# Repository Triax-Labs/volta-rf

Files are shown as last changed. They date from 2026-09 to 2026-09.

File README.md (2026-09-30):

# VoltaRF

VoltaRF is a homebrew software defined radio (SDR), it is based on parts found inside a cheap 'n old satellite DVB-S television receiver.





VoltaRF could Also be used as a good ol' development board around the CH32H417 flagship platform, all GPIOs are exposed!

## Background

Due to the fact that RTL-SDRs are quite hard to find locally (due to restrictions), I have decided to build my own alternative out of already existing and easily available appliances.

The RTL-SDR itself being a by product of a television related product, I decided to base my own SDR on satellite television receiver parts, most notably the RF tuner found inside those.

After some testing I was able of finding out one very common RF tuner chip, the RDA5815. When it was put to testing I was able of getting it to tune in the range of 50MHz and all the way up to 2.5GHz (covering amateur bands, ISM, commercial broadcasting as well as radionavigation and air traffic.)

The RDA5815 tuner claims a bandwidth range of 4MHz all the way up to 40MHz, thankfully the LPF is configurable over I2C. I can only guarantee 4MHz of bandwidth, unless we overclock the ADCs.

## Main Parts

- Qorvo's SGL0622Z (LNA)
- SkyWorks' RDA5815M (RF Interface & Tuner)
- WCH's CH32H417QEU6 (MCU, ADC and USB Interface)
  [Here you can find the entirety of the BOM.](https://github.com/Triax-Labs/volta-rf/blob/main/hardware/production/bom.csv)

## Production

Production is done through [JLCPCB](https://jlcpcb.com)'s PCBA service.

| Item | Price | Qty | Where |
| ---- | ----- | --- | --- |
| PCB  | $8 | 5 Boards | [JLCPCB](https://jlcpcb.com) |
| PCBA | $120  | 5 Boards | [JLCPCB](https://jlcpcb.com) |

_Those are estimated prices, and they don't include shipping._

Production files could be found inside `/hardware/production`, the BOM has been optimized for JLC's library of parts.

When ordering an assembled board, make sure all footprints are rotated in their right place with dots aligning.

Some parts don't exist on JLCPCB, so you will have to source and assemble them yourself, most notable one is the RDA5815M RF tuner chip, you can buy it from AliExpress instead.

---



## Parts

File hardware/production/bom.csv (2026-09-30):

Designator | Footprint | Quantity | Value | LCSC Part #
_4, _3, _2, |  | 4
C1, C10, C11, C15, C16, C17, C18, C19, C2, C20, C21, C22, C23, C24, C25, C26, C27, C28, C29, C30, C31, C32, C33, C34, C35, C36, C37, C38, C39, C40, C45, C46, C5, C50, C52, C6, C9 | C0402 | 37 | CL05B104KO5NNNC | C1525
C12, C13, C14 | C0603 | 3 | CL10A475KO8NNNC | C19666
C3, C4, C51 | C0402 | 3 | CL05A225MQ5NSNC | C12530
C41, C42 | C0402 | 2 | 0402B102K500NT | C1523
C43, C44 | C0402 | 2 | 0402CG150J500NT | C1548
C47, C48 | C0402 | 2 | 0402CG270J500NTN | C1557
C49 | C0603 | 1 | CL10A225KO8NNNC | C23630
C7, C8 | C0402 | 2 | CL05B104KB54PNC | C307331
CARD1 | TF-SMD_TF-021B-H265 | 1 | TF-021B-H265 | C498185
L1, L4 | L0603 | 2 | BLM18PG121SN1D_C14709 | C14709
L2, L3 | L0603 | 2 | SDCL1608C68NJTF | C13415
LED1 | LED-SMD_L1.6-W0.8-R-RD | 1 | KT-0603R | C2286
LED2 | LED0603-R-RD_WHITE | 1 | 0603White light_C2290 | C2290
R1, R2, R3, R4, R5, R8 | R0402 | 6 | 0402WGF220JTCE | C25092
R10, R19, R20, R21, R6, R7, R9 | R0402 | 7 | 0402WGF5601TCE | C25908
R11, R12, R13, R14, R15 | R0402 | 5 | 0402WGF1502TCE | C25756
R16, R17 | R0402 | 2 | 0402WGF3300TCE | C25104
R22, R23 | R0402 | 2 | 0402WGF499JTCE | C25120
R24, R25, R26 | R0402 | 3 | 0402WGF2001TCE | C4109
SW2 | SW-SMD_L3.9-W3.0-P4.45 | 1 | TS-1088-AR02016 | C720477
U1, U8 | HDR-TH_46P-P2.54-V-M-R2-C23-S2.54 | 2 | DS1021-2X23SF11-B | C7430419
U2 | QFN-128_L12.3-W12.3-P0.35-TL-EP9.0 | 1 | CH32H417QEU6_C49363240 | C49363240
U3 | VQFN-16_L3.0-W3.0-P0.50-BL-EP1.8 | 1 | CH9441P | C54300797
U4 | SOT-23-5_L3.0-W1.7-P0.95-LS2.8-BR | 1 | ME6217C33M5G | C427602
U7 | DFN-8_L2.0-W2.0-P0.50-TL-EP | 1 | SGL0622Z | C470895
USB1, USB2 | USB-C-SMD_TYPEC-324G-BCP24 | 2 | HC-TYPE-C-24P-035A | C48887178
X1 | CRYSTAL-SMD_4P-L3.2-W2.5-BL | 1 | X322525MOB4SI | C9006

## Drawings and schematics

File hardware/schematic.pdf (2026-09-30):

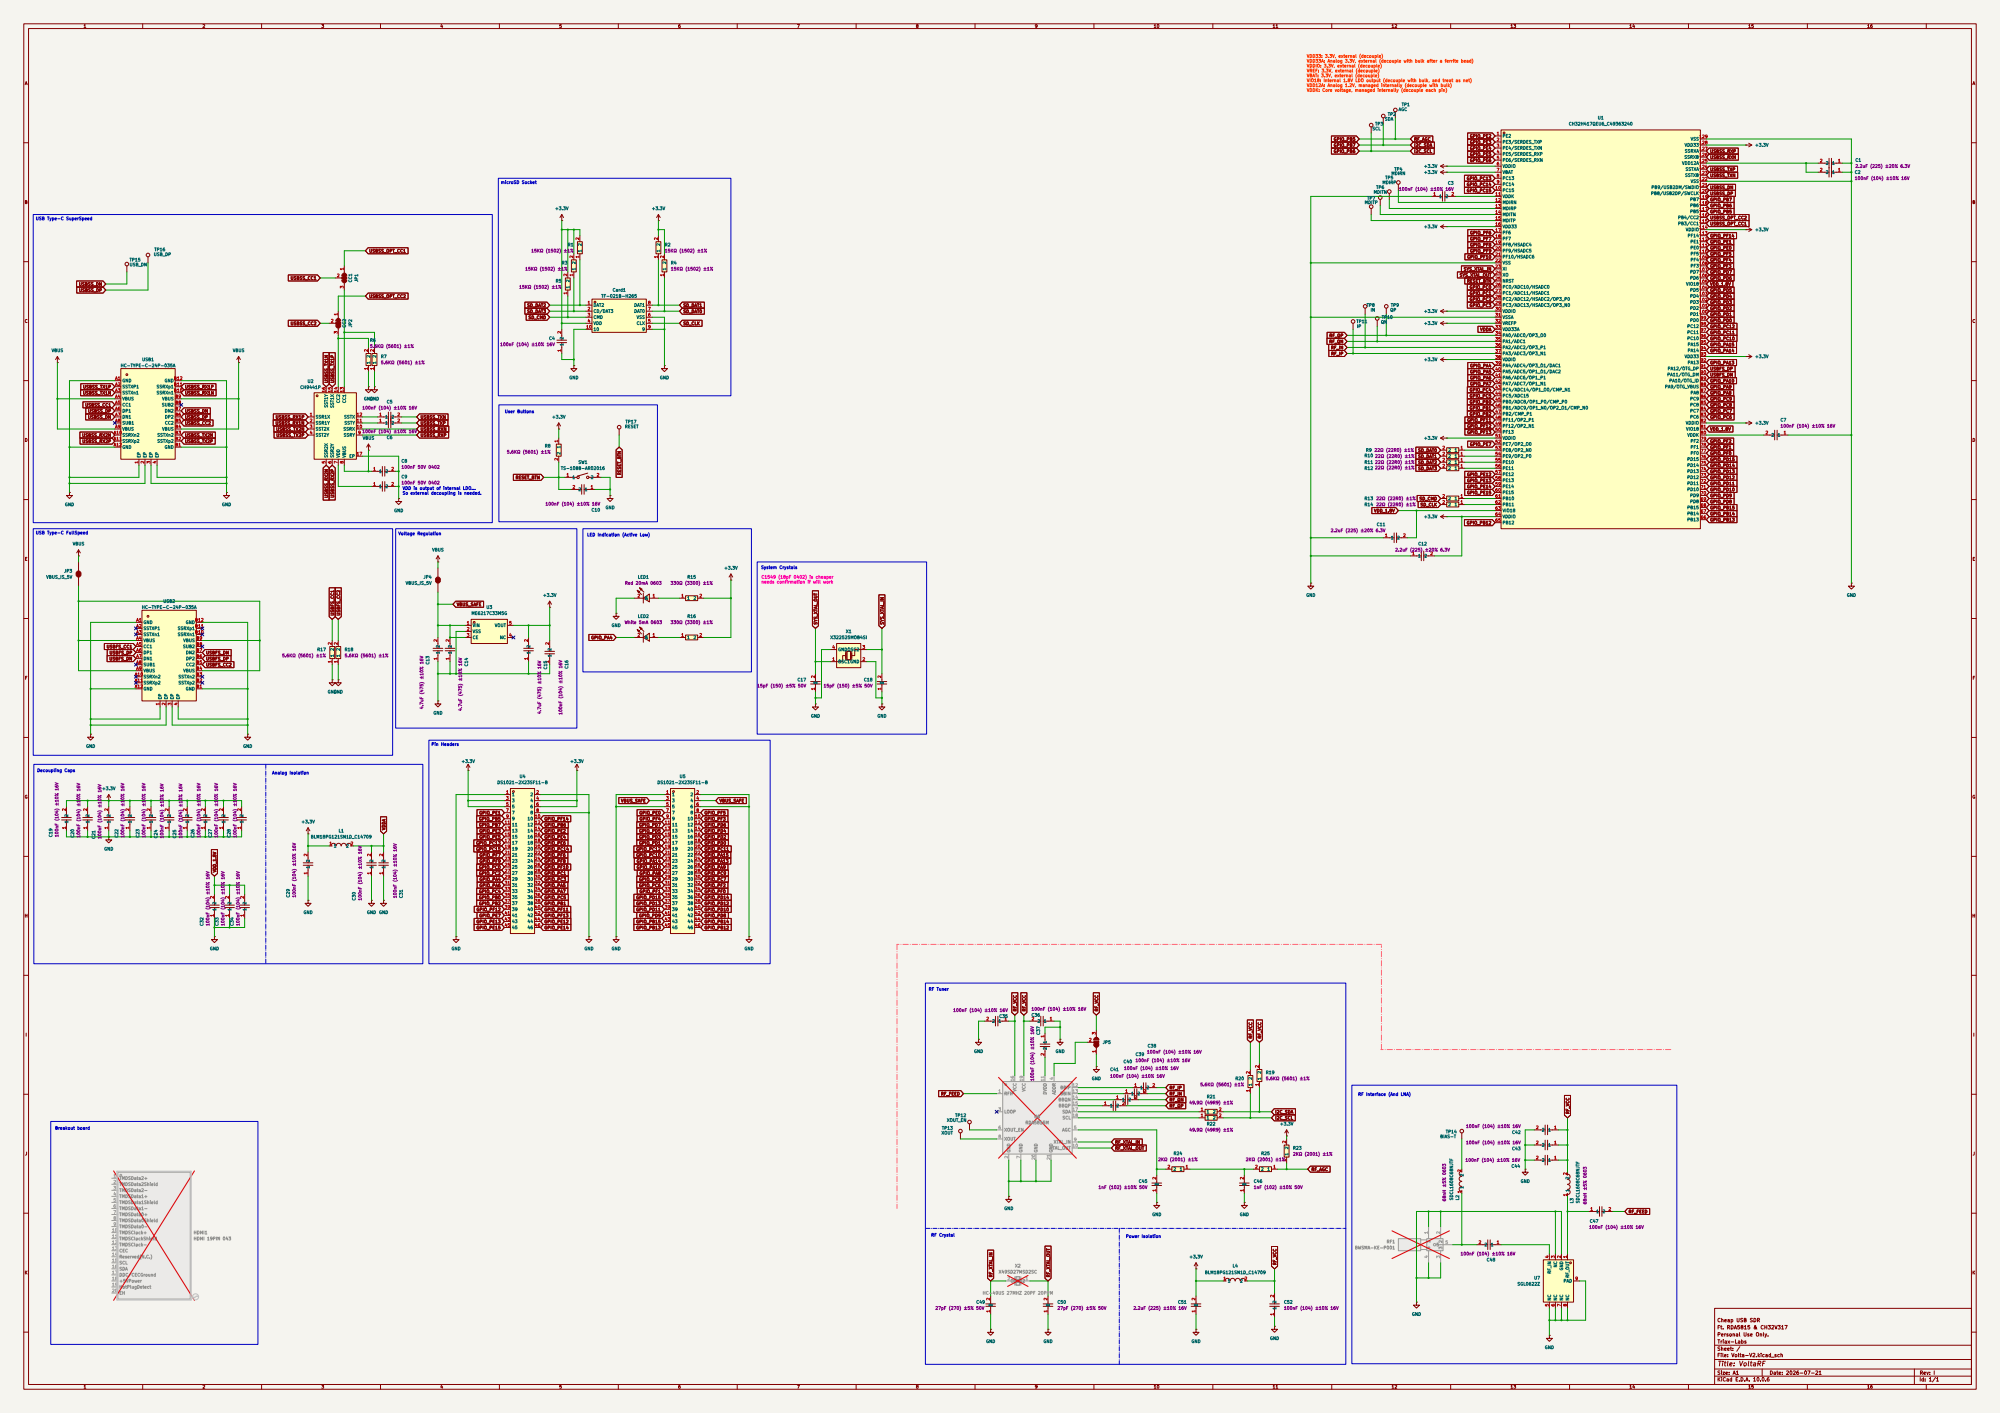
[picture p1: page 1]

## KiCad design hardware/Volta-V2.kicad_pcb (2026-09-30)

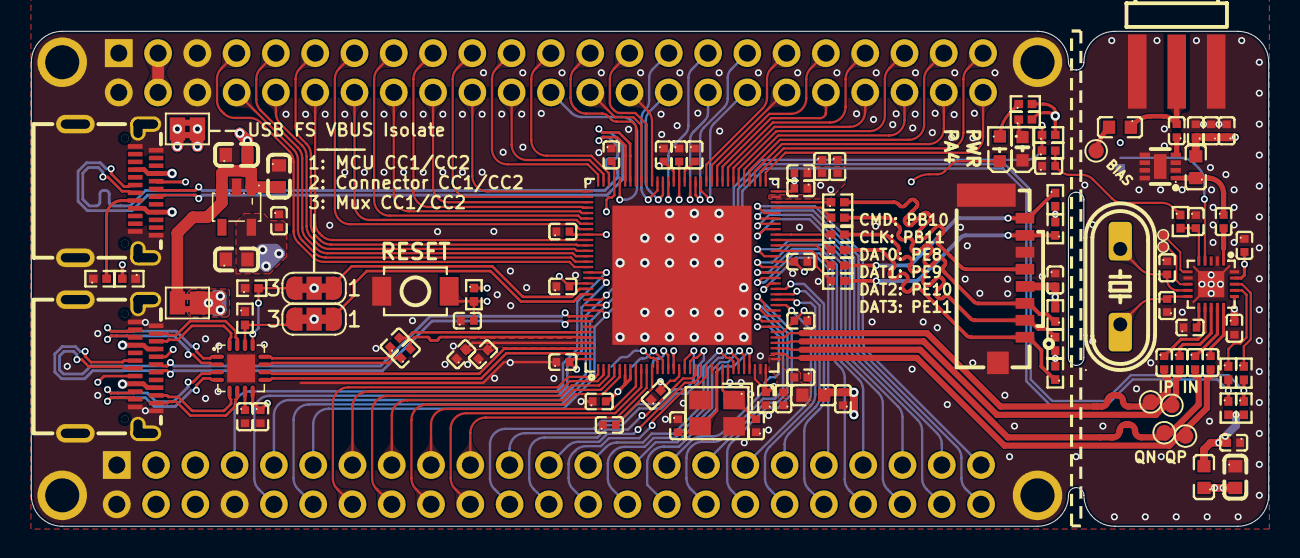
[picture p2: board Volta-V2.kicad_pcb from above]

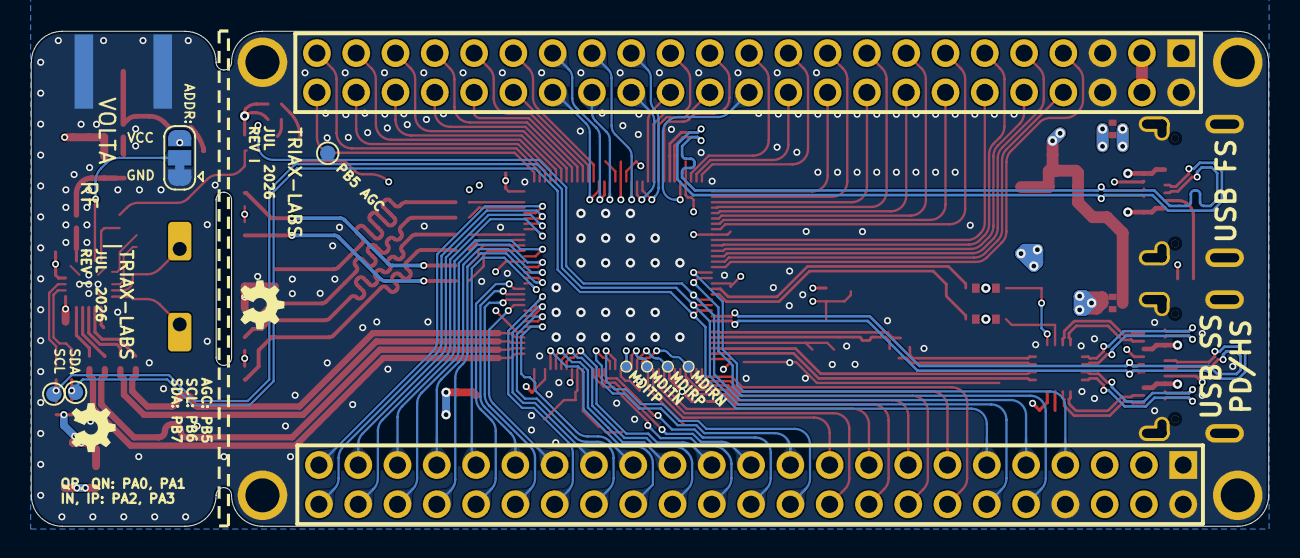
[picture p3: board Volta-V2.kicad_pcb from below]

Board: 4 copper layers, 80.0 x 32.0 mm, 116 parts (10 on the bottom side), 161 nets.

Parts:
C1, C2, C5, C6, C9, C10, C11, C15, C16, C17, C18, C19, C20, C21, C22, C23, C24, C25, C26, C27, C28, C29, C30, C31, C32, C33, C34, C35, C36, C37, C38, C39, C40, C45, C46, C50, C52: CL05B104KO5NNNC; C0402
C3, C4, C51: CL05A225MQ5NSNC; C0402
C7, C8: CL05B104KB54PNC; C0402
C12, C13, C14: CL10A475KO8NNNC; C0603
C41, C42: 0402B102K500NT; C0402
C43, C44: 0402CG150J500NT; C0402
C47, C48: 0402CG270J500NTN; C0402
C49: CL10A225KO8NNNC; C0603
Card1: TF-021B-H265; TF-SMD_TF-021B-H265
JP1: CC1; SolderJumper-3_P1.3mm_Bridged123_RoundedPad1.0x1.5mm_Number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
JP2: CC2; SolderJumper-3_P1.3mm_Bridged123_RoundedPad1.0x1.5mm_Number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
JP3, JP5: VBUS_IS_5V; SolderJumper-2_P1.3mm_Bridged2Bar_Pad1.0x1.5mm
JP4: SolderJumper_3_Bridged12; SolderJumper-3_P1.3mm_Bridged12_RoundedPad1.0x1.5mm
L1, L4: BLM18PG121SN1D_C14709; L0603
L2, L3: SDCL1608C68NJTF; L0603
LED1: KT-0603R; LED-SMD_L1.6-W0.8-R-RD
LED2: 0603White light_C2290; LED0603-R-RD_WHITE
R1, R2, R3, R4, R5, R8: 0402WGF220JTCE; R0402
R6, R7, R9, R10, R19, R20, R21: 0402WGF5601TCE; R0402
R11, R12, R13, R14, R15: 0402WGF1502TCE; R0402
R16, R17: 0402WGF3300TCE; R0402
R22, R23: 0402WGF499JTCE; R0402
R24, R25, R26: 0402WGF2001TCE; R0402
RF1: BWSMA-KE-P001; SMA-SMD_BWSMA-KE-P001
SW2: TS-1088-AR02016; SW-SMD_L3.9-W3.0-P4.45
TP1: MDIRN; 2xTinyTestPoint
TP2: MDIRP; 2xTinyTestPoint
TP3: MDITN; 2xTinyTestPoint
TP4: MDITP; 2xTinyTestPoint
TP5: IN; TestPoint_Pad_D1.0mm
TP6: QP; TestPoint_Pad_D1.0mm
TP7: QN; TestPoint_Pad_D1.0mm
TP8: IP; TestPoint_Pad_D1.0mm
TP9: AGC; TestPoint_Pad_D1.0mm
TP10: SDA; TestPoint_Pad_D1.0mm
TP11: SCL; TestPoint_Pad_D1.0mm
TP12: XOUT_EN; 2xTinyTestPoint
TP13: XOUT; 2xTinyTestPoint
TP14: BIAS-T; TestPoint_Pad_D1.0mm
U1, U8: DS1021-2X23SF11-B; HDR-TH_46P-P2.54-V-M-R2-C23-S2.54
U2: CH32H417QEU6_C49363240; QFN-128_L12.3-W12.3-P0.35-TL-EP9.0
U3: CH9441P; VQFN-16_L3.0-W3.0-P0.50-BL-EP1.8
U4: ME6217C33M5G; SOT-23-5_L3.0-W1.7-P0.95-LS2.8-BR
U6: RDA5815M; QFN-20_L3.0-W3.0-P0.40-TL-EP1.7
U7: SGL0622Z; DFN-8_L2.0-W2.0-P0.50-TL-EP
USB1, USB2: HC-TYPE-C-24P-035A; USB-C-SMD_TYPEC-324G-BCP24
X1: X322525MOB4SI; CRYSTAL-SMD_4P-L3.2-W2.5-BL
X2: X49SD27MSD2SC; HC-49US_L11.5-W4.5-P4.88

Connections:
+3.3V: C4.2, C14.2, C15.2, C16.2, C17.2, C20.2, C21.2, C22.2, C23.2, C24.2, C25.2, C26.2, C27.2, C28.2, C29.2, C49.2, Card1.4 (VDD), L1.1, L4.1, R11.2, R12.2, R13.2, R14.2, R15.2, R16.2, R17.2, R19.1, R24.2, U1.3, U1.4, U1.5, U1.6, U2.6 (VDDIO), U2.7 (VBAT), U2.16 (VDD33), U2.30 (VDDIO), U2.32 (VREFP), U2.38 (VDDIO), U2.51 (VDDIO), U2.64 (VDDIO), U2.82 (VDDIO), U2.93 (VDD33), U2.114 (VDDIO), U2.128 (VDD33), U4.5 (VOUT)
GND: C1.1, C2.1, C3.1, C4.1, C7.2, C8.2, C9.1, C10.1, C11.1, C12.1, C13.1, C14.1, C15.1, C16.1, C17.1, C18.1, C19.1, C20.1, C21.1, C22.1, C23.1, C24.1, C25.1, C26.1, C27.1, C28.1, C29.1, C30.2, C31.1, C32.1, C33.1, C38.2, C39.2, C40.2, C41.1, C42.1, C43.1, C44.1, C47.1, C48.1, C49.1, C50.1, C51.1, C52.1, Card1.6 (VSS), Card1.9, Card1.10, JP4.1 (A), LED1.2 (K), R6.1, R7.1, R9.1, R10.1, RF1.1, RF1.2, RF1.3, RF1.4, SW2.2, U1.1, U1.2, U1.8, U2.22 (VSS), U2.31 (VSSA), U2.122 (VSS), U2.129 (VSS), U3.17 (EP), U4.2 (VSS), U6.2 (GND), U6.7 (GND), U6.20 (GND), U6.21 (GND), U7.2 (GND), U7.3 (NC), U7.5 (NC), U7.6 (NC), U7.7 (NC), U7.8 (NC), U7.9 (PAD), U8.1, U8.2, U8.5, U8.6, USB1.1 (EP), USB1.2 (EP), USB1.3 (EP), USB1.4 (EP), USB1.A1 (GND), USB1.A12 (GND), USB1.B1 (GND), USB1.B12 (GND), USB2.1 (EP), USB2.2 (EP), USB2.3 (EP), USB2.4 (EP), USB2.A1 (GND), USB2.A12 (GND), USB2.B1 (GND), USB2.B12 (GND), X1.2 (GND), X1.4 (GND)
GPIO_PA4: LED2.2 (K), U1.29, U2.39 (PA4/ADC4/OP3_O1/DAC1)
GPIO_PA5: U1.32, U2.40 (PA5/ADC5/OP1_O1/DAC2)
GPIO_PA6: U1.31, U2.41 (PA6/ADC6/OP1_P1)
GPIO_PA7: U1.34, U2.42 (PA7/ADC7/OP1_N1)
GPIO_PA8: U2.87 (PA8), U8.27
GPIO_PA9: U2.88 (PA9/OTG_VBUS), U8.26
GPIO_PA10: U2.89 (PA10/OTG_ID), U8.25
GPIO_PA13: U2.92 (PA13), U8.24
GPIO_PA14: U2.94 (PA14), U8.23
GPIO_PA15: U2.95 (PA15), U8.22
GPIO_PB0: U1.35, U2.45 (PB0/ADC8/OP1_P0/CMP_P0)
GPIO_PB1: U1.38, U2.46 (PB1/ADC9/OP1_N0/OP2_O1/CMP_N0)
GPIO_PB2: U1.37, U2.47 (PB2/CMP_P1)
GPIO_PB5: R24.1, R26.1, TP9.1 (1_1), U1.9, U2.117 (PB5)
GPIO_PB6: R21.1, R23.2, TP11.1 (1_1), U1.12, U2.118 (PB6)
GPIO_PB7: R20.1, R22.2, TP10.1 (1_1), U1.11, U2.119 (PB7)
GPIO_PB12: U2.65 (PB12), U8.46
GPIO_PB13: U2.66 (PB13), U8.45
GPIO_PB14: U2.67 (PB14), U8.44
GPIO_PB15: U2.68 (PB15), U8.43
GPIO_PC0: U1.25, U2.26 (PC0/ADC10/HSADC0)
GPIO_PC1: U1.28, U2.27 (PC1/ADC11/HSADC1)
GPIO_PC2: U1.27, U2.28 (PC2/ADC12/HSADC2/OP3_P0)
GPIO_PC3: U1.30, U2.29 (PC3/ADC13/HSADC3/OP3_N0)
GPIO_PC4: U1.33, U2.43 (PC4/ADC14/OP1_O0/CMP_N1)
GPIO_PC5: U1.36, U2.44 (PC5/ADC15)
GPIO_PC6: U2.83 (PC6), U8.31
GPIO_PC7: U2.84 (PC7), U8.30
GPIO_PC8: U2.85 (PC8), U8.29
GPIO_PC9: U2.86 (PC9), U8.28
GPIO_PC10: U2.96 (PC10), U8.21
GPIO_PC11: U2.97 (PC11), U8.20
GPIO_PC12: U2.98 (PC12), U8.19
GPIO_PC13: U1.17, U2.8 (PC13)
GPIO_PC14: U1.20, U2.9 (PC14)
GPIO_PC15: U1.19, U2.10 (PC15)
GPIO_PD0: U2.99 (PD0), U8.18
GPIO_PD1: U2.100 (PD1), U8.17
GPIO_PD2: U2.101 (PD2), U8.16
GPIO_PD3: U2.102 (PD3), U8.15
GPIO_PD4: U2.103 (PD4), U8.14
GPIO_PD5: U2.104 (PD5), U8.13
GPIO_PD6: U2.106 (PD6), U8.12
GPIO_PD7: U2.107 (PD7), U8.11
GPIO_PD8: U2.69 (PD8), U8.42
GPIO_PD9: U2.70 (PD9), U8.41
GPIO_PD10: U2.71 (PD10), U8.40
GPIO_PD11: U2.72 (PD11), U8.39
GPIO_PD12: U2.73 (PD12), U8.38
GPIO_PD13: U2.74 (PD13), U8.37
GPIO_PD14: U2.75 (PD14), U8.36
GPIO_PD15: U2.76 (PD15), U8.35
GPIO_PE0: U2.111 (PE0), U8.7
GPIO_PE1: U1.7, U2.112 (PE1)
GPIO_PE2: U1.14, U2.1 (PE2)
GPIO_PE3: U1.13, U2.2 (PE3/SERDES_TXP)
GPIO_PE4: U1.16, U2.3 (PE4/SERDES_TXN)
GPIO_PE5: U1.15, U2.4 (PE5/SERDES_RXP)
GPIO_PE6: U1.18, U2.5 (PE6/SERDES_RXN)
GPIO_PE7: U1.41, U2.52 (PE7/OP2_O0)
GPIO_PE12: U1.44, U2.57 (PE12)
GPIO_PE13: U1.43, U2.58 (PE13)
GPIO_PE14: U1.46, U2.59 (PE14)
GPIO_PE15: U1.45, U2.60 (PE15)
GPIO_PF0: U2.77 (PF0), U8.34
GPIO_PF1: U2.78 (PF1), U8.33
GPIO_PF2: U2.79 (PF2), U8.32
GPIO_PF3: U2.108 (PF3), U8.10
GPIO_PF4: U2.109 (PF4), U8.9
GPIO_PF5: U2.110 (PF5), U8.8
GPIO_PF6: U1.22, U2.17 (PF6)
GPIO_PF7: U1.21, U2.18 (PF7)
GPIO_PF8: U1.24, U2.19 (PF8/HSADC4)
GPIO_PF9: U1.23, U2.20 (PF9/HSADC5)
GPIO_PF10: U1.26, U2.21 (PF10/HSADC6)
GPIO_PF11: U1.40, U2.48 (PF11/OP2_P1)
GPIO_PF12: U1.39, U2.49 (PF12/OP2_N1)
GPIO_PF13: U1.42, U2.50 (PF13)
GPIO_PF14: U1.10, U2.113 (PF14)
unnamed: C1.2, U2.11 (VDDK)
unnamed: C2.2, U2.80 (VDDK)
unnamed: C42.2, R25.1, R26.2
unnamed: C46.2, L2.1, RF1.5
unnamed: JP1.3 (B), R7.2, U3.13 (CC1)
unnamed: JP2.3 (B), R6.2, U3.14 (CC2)
unnamed: JP4.2 (C), U6.4 (ADDR)
unnamed: JP5.1 (A), USB2.A4 (VBUS), USB2.A9 (VBUS), USB2.B4 (VBUS), USB2.B9 (VBUS)
unnamed: L2.2, TP14.1 (1_1)
unnamed: LED1.1 (A), R16.1
unnamed: LED2.1 (A), R17.1
unnamed: TP1.1 (1_1), U2.12 (MDIRN)
unnamed: TP2.1 (1_1), U2.13 (MDIRP)
unnamed: TP3.1 (1_1), U2.14 (MDITN)
unnamed: TP4.1 (1_1), U2.15 (MDITP)
unnamed: R5.1, U2.61 (PB10)
unnamed: R8.1, U2.62 (PB11)
unnamed: R1.1, U2.53 (PE8/OP2_N0)
unnamed: R2.1, U2.54 (PE9/OP2_P0)
unnamed: R3.1, U2.55 (PE10)
unnamed: R4.1, U2.56 (PE11)
unnamed: C51.2, C52.2, U2.125 (VDD12A)
unnamed: C5.1, U3.12 (SSTX)
unnamed: C6.1, U3.11 (SSTY)
unnamed: C8.1, U3.7 (VDD)
unnamed: C41.2, R25.2, U6.5 (AGC)
unnamed: C35.1, U6.13 (BBIN)
unnamed: C34.1, U6.12 (BBIP)
unnamed: C36.1, U6.14 (BBQN)
unnamed: C37.1, U6.15 (BBQP)
unnamed: C32.2, U6.11 (DVDD)
unnamed: R23.1, U6.18 (SCL)
unnamed: R22.1, U6.17 (SDA)
unnamed: TP13.1 (1_1), U6.8 (XOUT)
unnamed: TP12.1 (1_1), U6.6 (XOUT_EN)
unnamed: C46.1, U7.4 (RF_IN)
unnamed: C45.1, L3.1, U7.1 (RF_OUT)
RESET_BTN: C33.2, R19.2, SW2.1, U2.25 (NRST)
RF_FEED: C45.2, U6.1 (RFIP)
RF_IN: C35.2, TP5.1 (1_1), U2.36 (PA2/ADC2/OP3_P1)
RF_IP: C34.2, TP8.1 (1_1), U2.37 (PA3/ADC3/OP3_N1)
RF_QN: C36.2, TP7.1 (1_1), U2.35 (PA1/ADC1)
RF_QP: C37.2, TP6.1 (1_1), U2.34 (PA0/ADC0/OP3_O0)
RF_VCC: C30.1, C31.2, C38.1, C39.1, C40.1, C50.2, JP4.3 (B), L3.2, L4.2, R20.2, R21.2, U6.16 (VCC), U6.19 (VCC)
RF_XTAL_IN: C47.2, U6.9 (XTAL_IN), X2.2 (OSC2)
RF_XTAL_OUT: C48.2, U6.10 (XTAL_OUT), X2.1 (OSC1)
SD_CLK: Card1.5 (CLX), R8.2
SD_CMD: Card1.3 (CMD), R5.2, R15.1
SD_DAT0: Card1.7 (DAT0), R1.2, R14.1
SD_DAT1: Card1.8 (DAT1), R2.2, R12.1
SD_DAT2: Card1.1 (DAT2), R3.2, R11.1
SD_DAT3: Card1.2 (CD/DAT3), R4.2, R13.1
SYS_XTAL_IN: C44.2, U2.23 (XI), X1.3 (OSC2)
SYS_XTAL_OUT: C43.2, U2.24 (XO), X1.1 (OSC1)
USBFS_CC1: R9.2, USB2.A5 (CC1)
USBFS_CC2: R10.2, USB2.B5 (CC2)
USBFS_DN: U2.90 (PA11/OTG_DM), USB2.A7 (DN1), USB2.B7 (DN2)
USBFS_DP: U2.91 (PA12/OTG_DP), USB2.A6 (DP1), USB2.B6 (DP2)
USBSS_CC1: JP1.2 (C), USB1.A5 (CC1)
USBSS_CC2: JP2.2 (C), USB1.B5 (CC2)
USBSS_DN: U2.121 (PB9/USB2DM/SWDIO), USB1.A7 (DN1), USB1.B7 (DN2)
USBSS_DP: U2.120 (PB8/USB2DP/SWCLK), USB1.A6 (DP1), USB1.B6 (DP2)
USBSS_OPT_CC1: JP1.1 (A), U2.115 (PB3/CC1)
USBSS_OPT_CC2: JP2.1 (A), U2.116 (PB4/CC2)
USBSS_RX1N: U3.2 (SSR1Y), USB1.B10 (SSRXn1)
USBSS_RX1P: U3.1 (SSR1X), USB1.B11 (SSRXp1)
USBSS_RX2N: U3.5 (SSR2X), USB1.A10 (SSRXn2)
USBSS_RX2P: U3.6 (SSR2Y), USB1.A11 (SSRXp2)
USBSS_RXN: U2.126 (SSRXB), U3.10 (SSRX)
USBSS_RXP: U2.127 (SSRXA), U3.9 (SSRY)
USBSS_TX1N: U3.16 (SST1Y), USB1.A3 (SSTXn1)
USBSS_TX1P: U3.15 (SST1X), USB1.A2 (SSTXP1)
USBSS_TX2N: U3.3 (SST2X), USB1.B3 (SSTXn2)
USBSS_TX2P: U3.4 (SST2Y), USB1.B2 (SSTXp2)
USBSS_TXN: C5.2, U2.123 (SSTXB)
USBSS_TXP: C6.2, U2.124 (SSTXA)
VBUS: C7.1, JP3.2 (B), JP5.2 (B), U3.8 (VBUS), USB1.A4 (VBUS), USB1.A9 (VBUS), USB1.B4 (VBUS), USB1.B9 (VBUS)
VBUS_SAFE: C12.2, C13.2, JP3.1 (A), U4.1 (VIN), U4.3 (CE), U8.3, U8.4
VDDA: C18.2, C19.2, L1.2, U2.33 (VDD33A)
VDD_1.8V: C3.2, C9.2, C10.2, C11.2, U2.63 (VIO18), U2.81 (VIO18), U2.105 (VIO18)

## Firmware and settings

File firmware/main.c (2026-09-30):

#include <stdio.h>

#include "ch32fun.h"

int main_V5F() {
    funPinMode(PE3, GPIO_CNF_OUT_PP, GPIO_Speed_180MHz);

    while (1) {
        funDigitalWrite(PE3, FUN_HIGH);
        Delay_Ms(250);
        funDigitalWrite(PE3, FUN_LOW);
        Delay_Ms(300);
    }
}

int main() {
    SystemInit();

    funGpioInitAll();  // Enable GPIOs

    StartV5F(main_V5F);

    funPinMode(PE2, GPIO_CNF_OUT_PP, GPIO_Speed_180MHz);
    funPinMode(PB0, GPIO_CNF_OUT_PP_AF, GPIO_Speed_180MHz);

    while (1) {
        funDigitalWrite(PE2, FUN_LOW);
        Delay_Ms(250);
        funDigitalWrite(PE2, FUN_HIGH);
        Delay_Ms(250);
    }
}

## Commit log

2026-07-23 upload initial hardware (schematic)
2026-07-24 AGC pin is now wired.
    also have added a programming header section in the GPIO header.
    [Volta-V1.kicad_pcb, Volta-V1.kicad_sch]
2026-07-24 finalize v1 and upload related documents
    [Volta-V1.kicad_pcb, Volta-V1.kicad_sch]
2026-07-25 add BOM
    [Volta-V1.kicad_pcb, bom.csv]
2026-08-03 add production files
    [bom.csv, designators.csv, positions.csv]
2026-09-30 feat: V2
    [Volta-V1.kicad_pcb, Volta-V1.kicad_sch, Volta-V2.kicad_pcb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]
2026-10-01 feat: add board STEP model

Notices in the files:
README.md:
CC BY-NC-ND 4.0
